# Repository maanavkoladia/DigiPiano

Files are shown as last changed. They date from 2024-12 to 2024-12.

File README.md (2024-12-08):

# DigiPiano

The **DigiPiano** is a velocity-sensitive digital piano designed using **STM32** and **ESP32** microcontrollers. It combines advanced sensor technology, high-quality audio playback, and Bluetooth connectivity to deliver a realistic and modern musical experience.

## Project Overview

- **Key Tracking Mechanism:**
  - Uses **Hall effect sensors** and magnets to detect key presses and releases.
  - Tracks key velocity to simulate the dynamics of a real piano.

- **Audio Playback:**
  - Plays pre-recorded piano note samples stored in external memory.
  - Outputs sound via AUX to speakers or streams wirelessly over Bluetooth.

- **Custom Sustain Circuitry:**
  - Includes a custom-designed sustain circuit to enhance the playing experience.

- **Communication Between Microcontrollers:**
  - The STM32 and ESP32 communicate efficiently using **SPI** and **UART** protocols, enabling seamless data exchange for key detection and audio output.

## Implementation Highlights

- The firmware handles multichannel analog data acquisition and processes it to detect key strokes with precision.
- Audio playback is managed through external memory, ensuring low-latency performance.
- Bluetooth functionality allows for wireless connectivity, enabling modern use cases such as streaming to Bluetooth speakers or devices.
- The hardware design incorporates a custom PCB layout for compactness and reliability, integrating sensors, microcontrollers, and audio components.

## See It in Action

Check out this [Instagram reel](https://www.instagram.com/reel/DDNmyurpquJ/?igsh=Y2NvNWVrb3MxazM1) to see the DigiPiano in action!

The DigiPiano is a versatile and user-friendly project, blending traditional piano functionality with modern digital and IoT capabilities.

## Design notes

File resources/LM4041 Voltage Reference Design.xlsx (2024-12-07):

Goal: design a shunt reference circuit
Jonathan Valvano, EE445L
Desired Vz | 1.5 | volts | 1) pick a desired reference voltage Vz (volts)
Vref | 1.233 | volts | LM4041 parameter
R1 | 47 | kohm | 2) choose a standard resistance value (kohm)
best R2 | 10.17761557 | kohm
Pick R2 | 10 | kohm | 3) pick a standard value for R2 close to best R2
Actual Vref | 1.495340426 | volts | Vz=Vref(1+R2/R1)
Vs | 3.3 | volts | V supply
Rin | 2 | kohm | 4) estimate input impedence on Vz (e.g., to DAC)
Iz | 0.08 | mA | LM4041 parameter
Iref | 0.02623404255 | mA | Vz/(R1+R2), Ohms Law, current through R1,R2
IL | 0.7476702128 | mA | Vz/Rin, Ohms Law, current through Rin
I total | 0.8539042553 | mA | Iz+Iref+IL
max Rs | 2.113421456 | kohm | (Vs-Vz)/Itotal
 |  |  | 5) choose Rs less than max Rs

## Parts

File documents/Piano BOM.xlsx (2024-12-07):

Quantity | REF DES | Type | Description | Manufacturer | Mfg. P/N | Distributor | P/N | Unit cost | Cost | Link | Current (mA)
1 | U | MCU | The TM4C123G LaunchPad evaluation kit is a low-cost evaluation platform for Arm Cortex-M4F based microcontrollers (MCUs). Featuring an 80-MHz Arm Cortex-M4F central processing unit, 256kB of flash and 32 kB of static random access memory, the TM4C123GH6PM MCU provides integrated USB 2.0 support for USB host/device/on-the-go and two 12-bit analog-to-digital converter modules. The TM4C123GH6PM also includes a multitude of serial communication channels such as UART, SPI, I2C, and CAN. The design of the TM4C123G LaunchPad highlights the TM4C123GH6PM USB 2.0 device interface and additional device features such as the hibernation and PWM modules. The EK-TM4C123GXL includes programmable user buttons and an RGB LED for custom applications. The stackable headers provide the interface to connect BoosterPack™ plug-in modules and make it easy and simple to expand the functionality of the TM4C123G LaunchPad through the Texas Instruments BoosterPack ecosystem. The TI-developed TivaWare SDK provides drivers for all peripherals and example code for dozens of applications for the TM4C123G LaunchPad. | TI | EK-TM4C123GXL | TI | EK-TM4C123GXL | 16.99 | 16.99 | https://www.ti.com/tool/EK-TM4C123GXL#order-start-development | 35mA
1 | IC | IC | The TM4C123GH6PM microcontroller is targeted for industrial applications, including remote monitoring, electronic point-of-sale machines, test and measurement equipment, network appliances and switches, factory automation, HVAC and building control, gaming equipment, motion control, transportation, and fire and security. | TI | TM4C123GH6PMIR | TI |  | $9.19 | $9.19 | https://www.ti.com/product/TM4C123GH6PM/part-details/TM4C123GH6PMIR | 30-35 mA, assuming 80Mhz and using perifs
1 | U | MCU | About this item 2.4GHz Dual Mode WiFi + Bluetooth Development Board Ultra-Low power consumption, works perfectly with the Arduino IDE Support LWIP protocol, Freertos SupportThree Modes: AP, STA, and AP+STA ESP32 is a safe, reliable, and scalable to a variety of applications | Espressif | ESP32-WROOM | HiLetgo | ESP-Wroom-32D | $9.99 | $9.99 | https://www.amazon.com/HiLetgo-ESP-WROOM-32-Development-Microcontroller-Integrated/dp/B0718T232Z | 170mA
3 | IC | multichannel-adc | he MCP3008 10-bit Analog-to-Digital Converter (ADC) combines high performance and low power consumption in a small package, making it ideal for embedded control applications. The MCP3008 features a successive approximation register (SAR) architecture and an industry-standard SPI serial interface, allowing 10-bit ADC capability to be added to any PIC® microcontroller. The MCP3008 features 200k samples/second, 8 input channels, low power consumption (5nA typical standby, 425µA typical active), and is available in 16-pin PDIP and SOIC packages. Applications for the MCP3008 include data acquisition, instrumentation and measurement, multi-channel data loggers, industrial PCs, motor control, robotics, industrial automation, smart sensors, portable instrumentation and home medical appliances. | MicroChip | MCP3008 | DigiKey | MCP3008-I/P-ND | $3.12 | $9.36 | https://www.digikey.com/en/products/detail/microchip-technology/MCP3008-I-P/319422 | 300uA
24 | U | sensor | 40Pcs 49E Hall Element S49E SS49E Linear Hall Element Linear Hall Effect Sensors 3 Pins Sensor Element Switch OH49E TO-92S | HoneyWell | SS49E | Jessine | S49E SS49E | $0.32 | $7.77 | https://www.amazon.com/JESSINIE-Element-Linear-Effect-Sensors/dp/B0BXDMRHF8 | 6mA
24 |  | magnet | gerator Magnets 50 Pcs, 10x3mm Tiny Round Disc Small, Muti-use Premium Neodymium Fridge Magnets Rare Earth, Whiteboard Magnets for Crafts, DIY, Office, Dry Erase Board |  |  | VSKIZ |  | $0.13 | $3.35 | https://www.amazon.com/VSKIZ-Refrigerator-Muti-use-Neodymium-Whiteboard/dp/B0BVY5VYQY
24 |  | springs | Made of copper, ,The piano spring adopts fine workmanship, good elasticity and long service life. The piano jack springs are made of high quality brass material and . Replacement piano action part to replace worn, weak or broken jack springs. Remove action, remove spring, clear hole, add drop of glue, put in new spring, put action back in These springs can be used on upright piano keys to replace keys that are not functioning properly due to worn springs |  |  | BQLZR |  | $0.11 | $2.66 | https://www.amazon.com/BQLZR-Golden-Copper-Upright-Replacement/dp/B017OYX4MU
1 | IC | 16bit DAC | AD5541A Digital to Analog Converter (DAC) Data Acquisition Pmod™ Platform Evaluation Expansion Board | Digilent | Pmod DA3 | DigiKey | 1286-1089-ND | $35.99 | $35.99 | https://www.digikey.com/en/products/detail/digilent-inc/410-241/4090066 | 20mA
1 | U | speaker |  |  |  |  |  |  |  |  |  | not sure about this yet
1 | U | linear reg | Linear Voltage Regulator IC Positive Fixed 1 Output 500mA TO-220-3 | TI | LM2937ET-3.3/NOPB | DigiKey | LM2937ET-3.3/NOPB-ND | $1.81 | $1.81 | https://www.digikey.com/en/products/detail/texas-instruments/LM2937ET-3-3-NOPB/363870 | 50uA
1 | IC | microSD Spi brekout | 5PCS Micro SD Card Reader Module Memory Storage Mini TF Card Adapter SPI Interface Breakout Board for Arduino for Raspberry Pi with 40P Jumper Cable | Stededu |  |  |  | $1.80 | $1.80 | https://www.amazon.com/Interface-Arduino-Raspberry-Breakout-Cable%EF%BC%88Pack/dp/B07MTTLF75?s=electronics | 20mA

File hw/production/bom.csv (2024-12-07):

Designator | Footprint | Quantity | Value | LCSC Part #
C1, C2 | CP_Radial_Tantal200mil | 2 | 1uF
C10, C12, C14, C4, C5 | C_Axial_200mil | 5 | 0.1uF
C11, C8 | C_Axial_200mil | 2 | 1uF
C13, C9 | C_Axial_200mil | 2 | 0.01uF
C15 | C_Axial_200mil | 1 | 10uF
C3 | CP_Radial_Tantal200mil | 1 | 2.2uF
C6, C7 | C_Axial_200mil | 2 | 10pF
IC1 | QFP50P1200X1200X160-64N | 1 | TM4C123GH6PMIR
J10_ADC1 | Molex_KK-254_AE-6410-04A_1x04_P2.54mm_Vertical | 1 | ADC1
J11_ADC3 | Molex_KK-254_AE-6410-04A_1x04_P2.54mm_Vertical | 1 | ADC3
J12 | AMASS_XT30UPB-M_1x02_P5.0mm_Vertical | 1 | 3.3V Pads
J13 | AMASS_XT30UPB-M_1x02_P5.0mm_Vertical | 1 | 5V Pads
J1_BARREL | BarrelJack_SwitchcraftConxall_RAPC10U_Horizontal | 1 | Barrel_Jack
J2_JTAG | PinHeader_1x05_P2.54mm_Vertical | 1 | Header_5
J3_DAC | Molex_KK-254_AE-6410-06A_1x06_P2.54mm_Vertical | 1 | Conn_01x06_Socket_DAC
J8_SDCARD | Molex_KK-254_AE-6410-11A_1x11_P2.54mm_Vertical | 1 | LCD SD HEADERS
J9_ADC2 | Molex_KK-254_AE-6410-04A_1x04_P2.54mm_Vertical | 1 | ADC2
R1 | R_Axial_DIN0204_L3.6mm_D1.6mm_P7.62mm_Horizontal | 1 | 10k
R2 | R_Axial_DIN0204_L3.6mm_D1.6mm_P7.62mm_Horizontal | 1 | 1M
SW1 | SW_PUSH_6mm | 1 | RESET
TP13, TP14, TP19, TP20, TP21, TP22, TP23 | Pin_D1.0mm_L10.0mm | 7 | TestPoint
U101_LP_STANDALONE, U30_BACKUP | ti_EKTM4C123GXL | 2 | EK-TM4C123GXL
U29 | T03B | 1 | LM2937ET-3.3/NOPB
U31_ESP32 | MODULE_ESP32-DEVKITC | 1 | ESP32-DEVKITC
Y1 | ABM3 | 1 | ABM3-16.000MHZ-B2-T

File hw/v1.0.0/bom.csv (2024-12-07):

Designator | Footprint | Quantity | Value | LCSC Part #
C101, C102 | C_Axial_L5.1mm_D3.1mm_P15.00mm_Horizontal | 2 | 100nF
C103, C104 | CP_Axial_L10.0mm_D4.5mm_P15.00mm_Horizontal | 2 | 4.7uF
D101 | D_5W_P12.70mm_Horizontal | 1 | 1V0
J101 | Samtec_HPM-02-01-x-S_Straight_1x02_Pitch5.08mm | 1 | EXT_3V3
LS101 | PinHeader_1x02_P2.54mm_Vertical | 1 | Speaker
Q101 | vishay_IRLD024PBF | 1 | IRLD024PBF
R101 | R_Axial_DIN0411_L9.9mm_D3.6mm_P15.24mm_Horizontal | 1 | 10k
SW101 | SW_PUSH_6mm | 1 | UP
SW102 | SW_PUSH_6mm | 1 | DOWN
SW103 | SW_PUSH_6mm | 1 | LEFT
SW104 | SW_PUSH_6mm | 1 | RIGHT
SW105 | SW_PUSH_6mm | 1 | MODE
U101 | ti_EKTM4C123GXL | 1 | EK-TM4C123GXL
U102 | ai_thinker_ESP8266_01 | 1 | ESP8266-01/ESP-01
U103 | adafruit_st7735r | 1 | Adafruit ST7735R

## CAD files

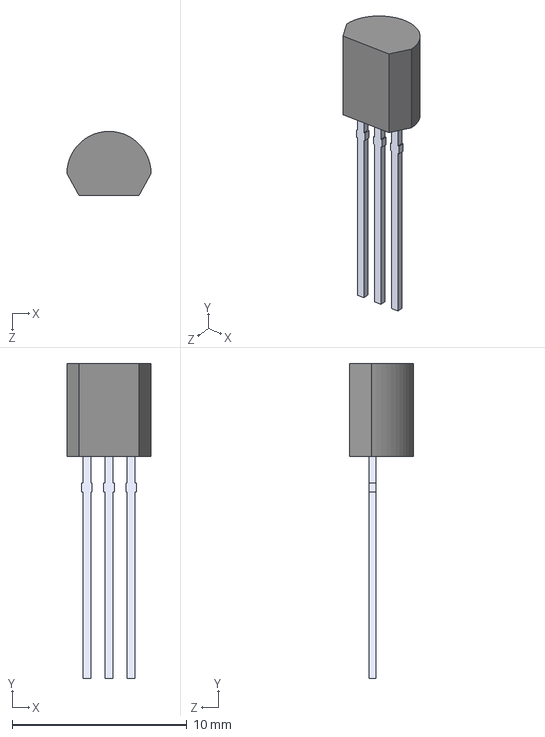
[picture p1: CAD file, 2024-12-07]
hw/models/ti_LM4041CILPR.step
4.82 x 18.0 x 3.68 mm

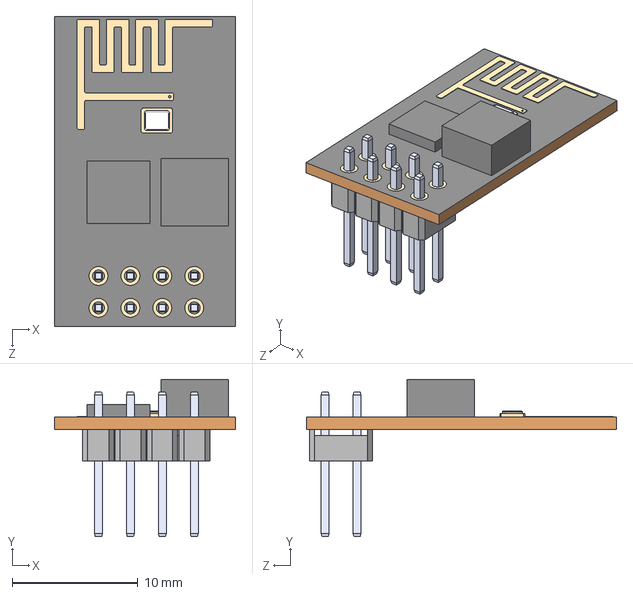
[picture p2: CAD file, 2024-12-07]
hw/models/ai_thinker_ESP8266-01.step
14.4 x 12.5 x 24.7 mm

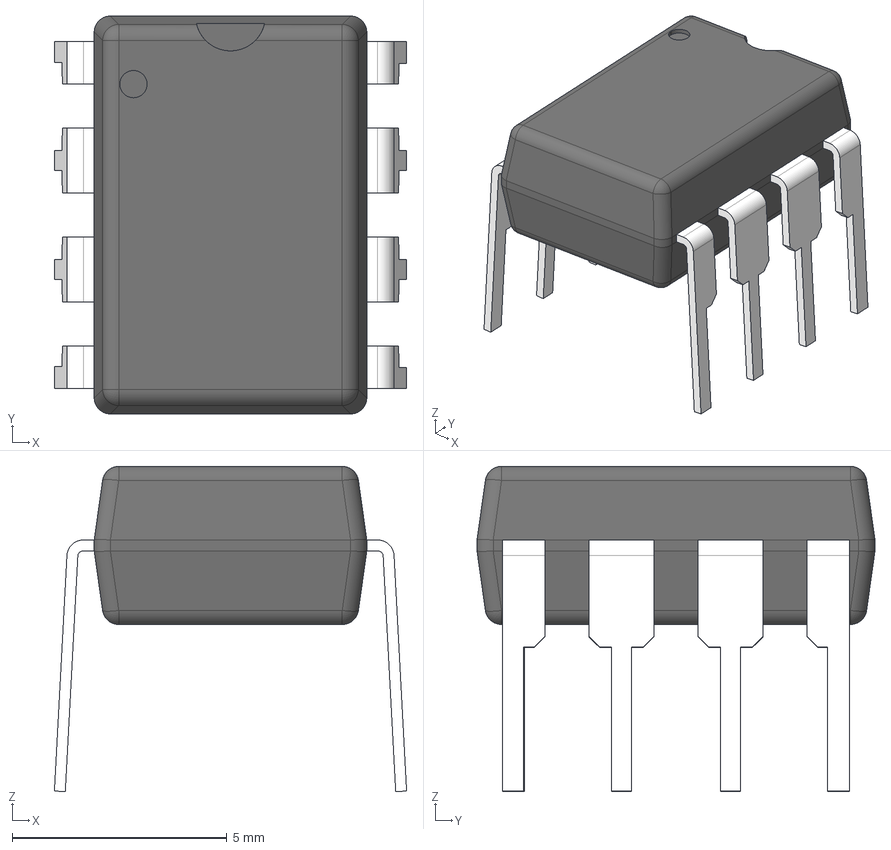
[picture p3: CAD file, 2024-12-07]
hw/models/ti_TLV5618AIP.stp
8.20 x 9.27 x 7.58 mm
BODY_P0008A
LEAD_P0008A x 4
LD_LHALF_P0008A x 2
LD_RHALF_P0008A x 2

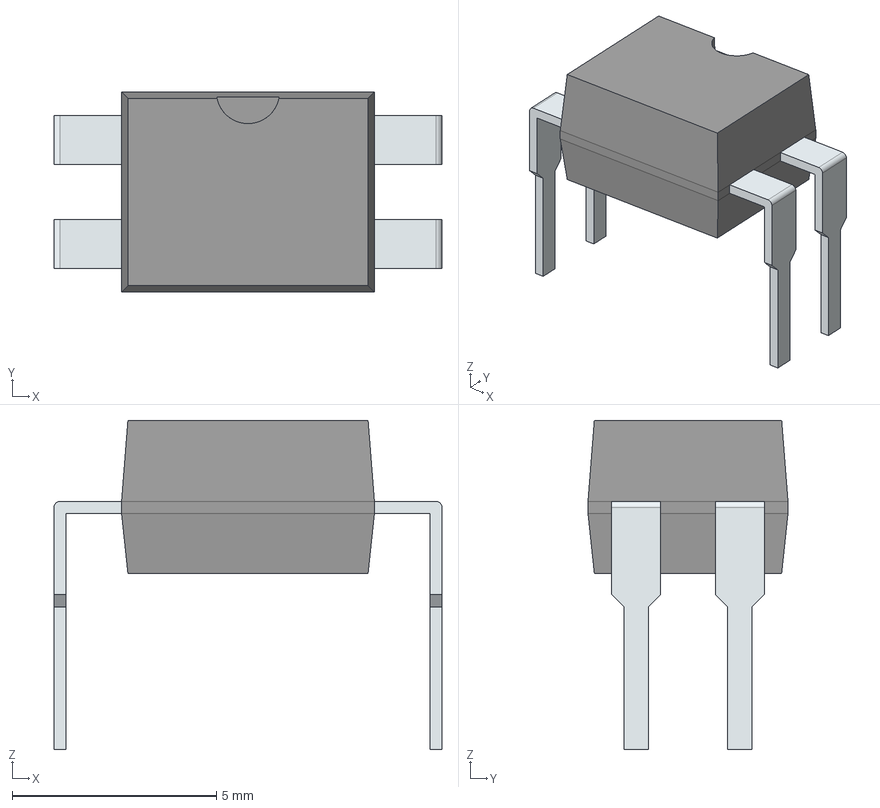
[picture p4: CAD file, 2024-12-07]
hw/models/vishay_IRLD024PBF.stp
9.51 x 4.90 x 8.07 mm
PinsArrayLR

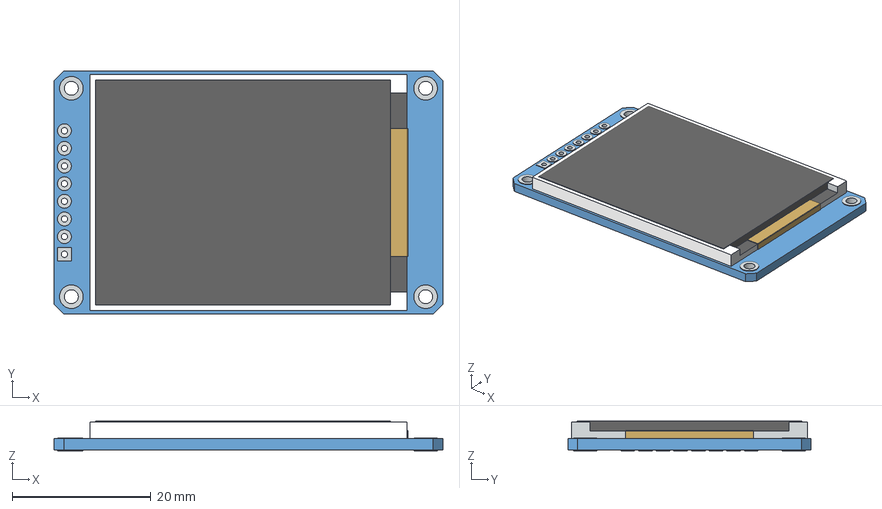
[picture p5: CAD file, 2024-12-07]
hw/models/adafruit_st7735r.stp
56.0 x 35.0 x 4.25 mm

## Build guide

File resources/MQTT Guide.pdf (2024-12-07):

## Contents

Lab 4 MQTT Writeup | 2

The Mobile App makes a change to thermostat temperature or

1

## Lab 4 MQTT Writeup

Key Aspects of MQTT

MQTT (Message Queuing Telemetry Transport), is a lightweight messaging protocol designed for low-bandwidth, high-latency, and unreliable networks. Developed in 1999 by IBM, MQTT is now a widely used open standard. MQTT is useful as it can:

- Organize data at the protocol level
- Cordinate actions between IOT devices
- Allow easy centralization of data to user-facing dashboards
- Send connected clients only the data they need
- Ensure a Quality Of Service (QOS) of data sent by clients

MQTT topology and the Publish/Subscribe Model:

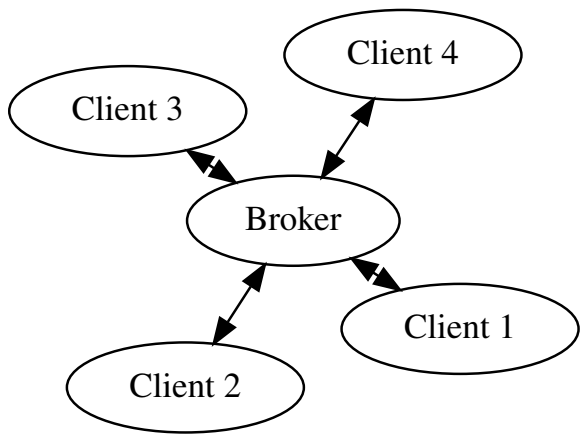
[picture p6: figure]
Broker; Client 1; Client 2; Client 3; Client 4

Figure 1: MQTT Client-Broker topology

MQTT includes ONLY broker to client/client to broker comunications. MQTT networks have one broker which facilitates comunication between many clients.

MQTT uses a Publish/Subscribe Model. In this model, data movement is controled by topics. Clients decide what data they recive, by deciding what topics they subscribe to. Clients can influence where data is sent by choosing what topic they attach to the data they publish. The messages sent and recived allways consist of a topic & data.

Although the broker is responsible for relaying data, it has no discresion to decide where data goes. The broker will relay a published message from any client to all clients that are subscribed to the topic of the message.

2

Topic Naming scheme:

An MQTT topic is a hierarchical string identifier that categorizes messages being published/subscribed to within the MQTT system. Topics are represented as strings and are organized hierarchically using forward slashes (‘/’). For example, a topic could be

"sensors/temperature/EER/floor1/embeddedlab."

or

"EER/floor1/embeddedlab/temperature"

How topics are defined are up to you. As long as they follow the typical hierarchical format.

Example of MQTT Communication

Here is an example of a typical MQTT communication between clients and how the broker routes it.

1. An MQTT client publishes a message to a specific topic on the MQTT broker.
2. The MQTT broker receives the published message and examines the topic.
3. The broker checks its subscription database to determine which MQTT client have subscribed to that topic.
4. The broker forwards the message to all subscribed clients
5. Subscribed MQTT clients receive the message and can take action based on its content.

Now lets imagine a scenario where we have a IoT setup in the EER. We have a three sensors which are their very own internet conected devices located in the EER. We have a temperature sensor in the 445L lab room, a thermostat located in the 319K room (let’s imagine the thermostat controls the A.C for the entirety of floor 1), and a faculty member has a mobile app that allows him to control the thermostat or see the readings from the sensors.

Here we have three clients:

- 445L Temperature Sensor
– Can read temperature in the 445L room
- 319K Lab Thermostat
– Connected via wire to the A.C, can control the A.C for the entirety of floor 1.
– Has its own temperature sensor that allows it to read the temperature in the room it is in (the 319K lab in this case)

3

– Has a temperature the thermostat can be set too. If the temperature in any of the rooms dip/rise above this temperature. The A.C is enabled to heat/cool
– Has a mode for the A.C. The A.C can either be off, set to cool, or set to heat.
– Can interface with external temperature sensors (such as the 445L temperature sensor)
– This closely resembles popular IoT thermostats such as the Nest or Ecobee
- Mobile App
– Allows you to control the thermostat (mode, set temperature)
– Read the temperature readings across all temperature sensors

All of these clients are connected to one central server (The MQTT Broker) to faciliate communication. This server could be for examples McDermott MQTT server in his office, or a public/cloud based MQTT Server.

Figure 2: Client-Broker setup of the Example

Now lets try to analyze what information each client provides, and what information each client would want from another client.

- 445L Temperature Sensor
– Reads the 445l lab room temperature, publishes it.
- 319K Lab Thermostat
– Reads the temperature in the 319K room, can act on this reading (enable the A.C for floor 1). Can also publish it (for the mobile app) – Is interested in the temperature in the 445L room, can act on this reading (enable the A.C for floor 1)
– Has a temperature that can be set to enable cooling/heat (acting on this data) It can publish this temperature (for the mobile app), and it can also have this changed externally (from the mobile app)
– Has a A.C mode (off/cool/heat). It acts on this mode (enable the A.C for cool/hot if the outside temperature changes). It can publish this data (so the mobile app knows the current A.C mode), it can also have this changed externally (from the mobile app)
- Mobile App
– Can set the A.C mode from the mobile app. Changes to this can be made from app or thermostate

4

– Can set the thermostat temperature. Changes can be made from app or thermostat.
– Can read all temperature sensor readings.

From this lets define the following topics, and these publishers and subscribers

- /EER/floor1/445Lab/temperature
- Publishers:
- 445L Temperature Sensor
- Subscribers:
- 319K Thermostat
- Mobile App
- /EER/floor1/319KLab/temperature
- Publishers:
- 319K Thermostat
- Subscribers:
- Mobile App
- /EER/floor1/thermostat/set_temp
- Publishers:
- 319K Thermostat
- Mobile App
- Subscribers:
- 319K Thermostat
- Mobile App
- /EER/floor1/thermostat/mode
- Publishers:
- 319K Thermostat
- Mobile App
- Subscribers:
- 319K Thermostat
- Mobile App

The scenario where 445L Lab Temp Changes

If the 445L lab room temperature changes. The sensor publishes to its topic its payload.

5

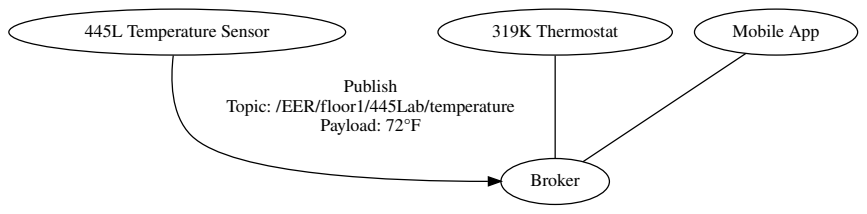
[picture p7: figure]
Broker; 445L Temperature Sensor; Publish Topic: /EER/floor1/445Lab/temperature Payload: 72°F; 319K Thermostat; Mobile App

Figure 3: 445L Temperature Sensor publishes change

The thermostat, and mobile app are subscribers and therefore notified.

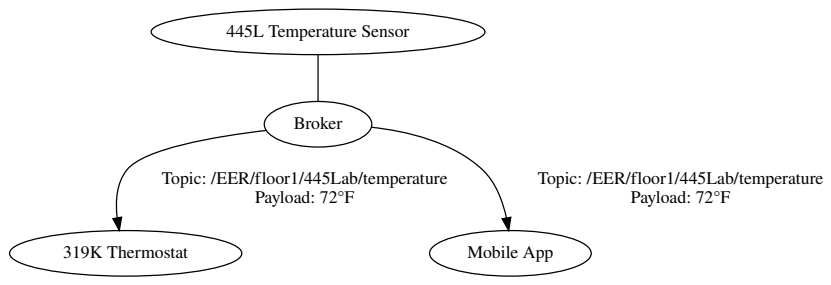
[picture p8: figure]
Broker; 319K Thermostat; Topic: /EER/floor1/445Lab/temperature Payload: 72°F; Mobile App; 445L Temperature Sensor

Figure 4: Subscribers are notified

The thermostat could act on this change. For example if the temperature 72°F exceeds/below the set temperature, it could enable the A.C. The mobile app also now has up-to date sensor reading.

The scenario where 319K Lab temp changes.

The thermostat has it’s own temperature sensor measuring the temperature of the 319K room. The thermostat can act this temperature (enable the A.C for example). But the mobile app also wants to be up-to date regarding all temperature readings.

6

Figure 5: Thermostat Temperature Sensor publishes change

The mobile app is subscribed to the all temperature readings, including the

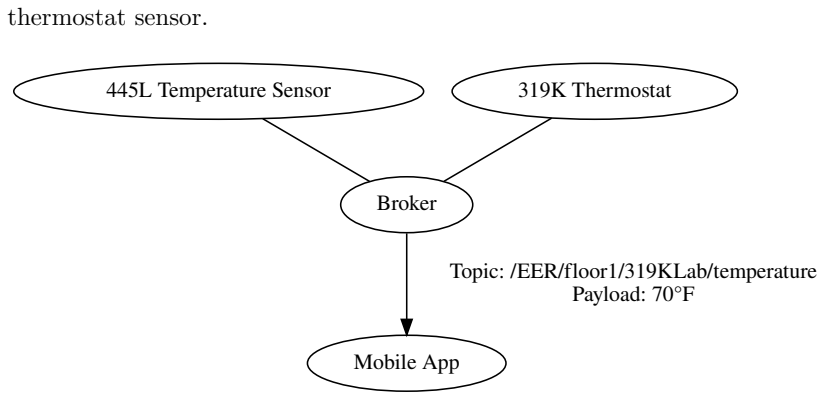
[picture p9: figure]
thermostat sensor.; Broker; Mobile App; Topic: /EER/floor1/319KLab/temperature Payload: 70°F; 445L Temperature Sensor; 319K Thermostat

Figure 6: Subscribers are notified

Thermostat has a change in set temperature or mode.

If you were to change the set temperature on the thermostat.

Figure 7: Thermostat Set Temp changes

The mobile app will be notified.

7

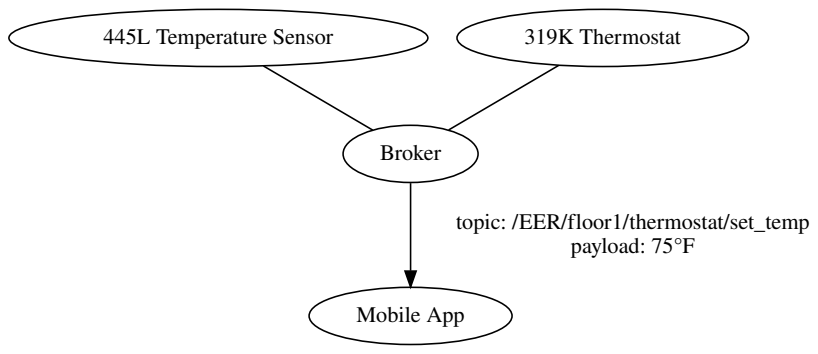
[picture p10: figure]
Broker; Mobile App; topic: /EER/floor1/thermostat/set_temp payload: 75°F; 445L Temperature Sensor; 319K Thermostat

Figure 8: Subscribers are notified

Similarily if you were to change the mode from “heat” to “cool” on the thermostat

Figure 9: Thermostat Set Temp changes

The mobile app will be notified.

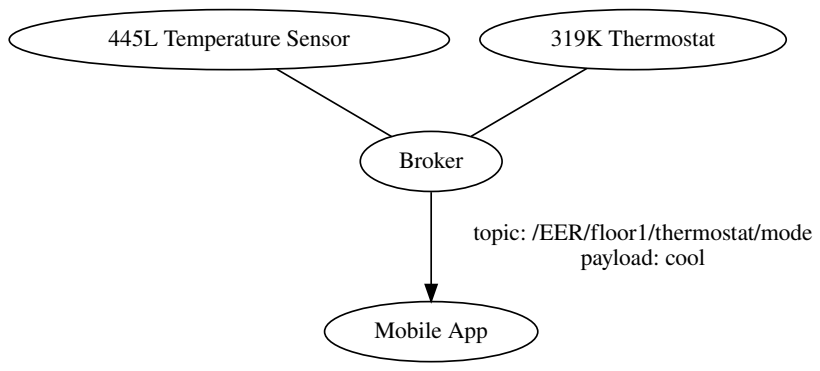
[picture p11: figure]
Broker; Mobile App; topic: /EER/floor1/thermostat/mode payload: cool; 445L Temperature Sensor; 319K Thermostat

Figure 10: Subscribers are notified

8

The Mobile App makes a change to thermostat temperature or mode

If we want to change the set temperature of the thermostat from the mobile app.

Figure 11: Thermostat Set Temp changes from Mobile App

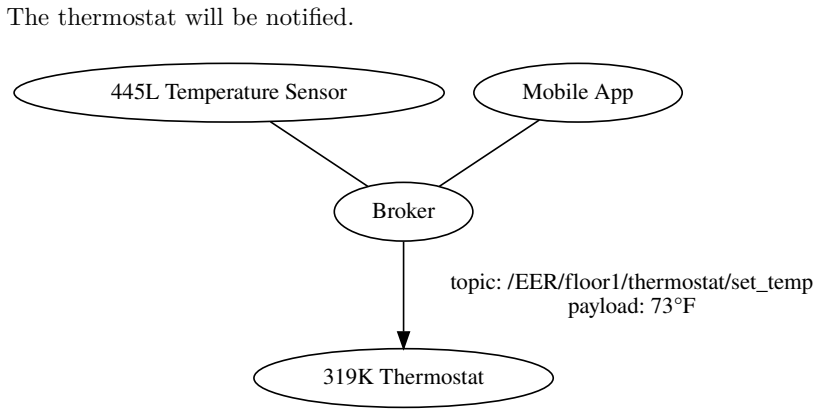
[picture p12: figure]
The thermostat will be notified.; Broker; 319K Thermostat; topic: /EER/floor1/thermostat/set_temp payload: 73°F; 445L Temperature Sensor; Mobile App

Figure 12: Subscribers are notified

Similarily if we want to turn off the A.C from the mobile app.

Figure 13: Thermostat Mode changes from Mobile App

The thermostat will be notified.

9

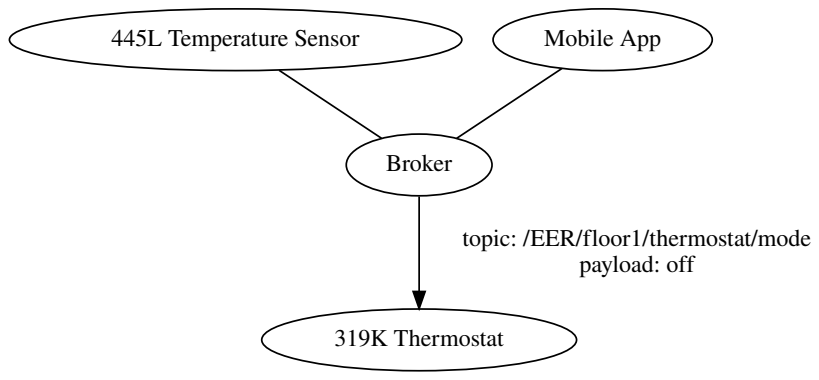
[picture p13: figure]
Broker; 319K Thermostat; topic: /EER/floor1/thermostat/mode payload: off; 445L Temperature Sensor; Mobile App

Figure 14: Subscribers are notified

How to approach Lab 4

From the perspective of the lab we have two clients:

- Your Alarm Clock
- The web dashboard

and a broker (the free broker service we are using called emqx.io).

From the perspective of the free broker service however, it has your alarm clock and web dashboard as a client. As well as the alarm clock and web dashboard of everyone else in the class (and anyone else using the service). So when you define your topics make sure the topic string is unique. For example if everyone used the same topic, lets say “alarm/current_time”, you would be able to change the time of everyones alarm clock. So to make unique topic names, your topic should start with your eid, ex. “eid123/alarm/current_time”.

Here is how we reccomend approaching this lab to avoid stress and headaches. First things first, don’t try integrating lab3 right away, instead get topics working.

Using the starter code, do the following.

1. ESP Bring up, the ESP8266 should be able to connect to a network and to the broker. This should be done in prep. Come to your TA’s if you were unable to do this.
2. Define your topics, and the subscriber/publisher relationships.
3. Have both of you open the web dashboard. Have one person subscribe to a topic, and have the other publish to the topic. The subscriber should be able to receive a message when this happens.
4. Modify your TM4C starter code so you can communicate with the ESP. The TM4C communicates with the ESP over UART. You can observe what

10 is being sent to the ESP via USB-Serial between your PC and the TM4C using a serial terminal.
5. Test, can you publish to a topic from the TM4C, do you see this change reflected on the web dashboard?
6. Test, can you publish to a topic from the web dashboard, do you see this change reflected on the TM4C?
7. Now that you can publish/subscribe to topics. Now integrate your Lab 3 Code.

If you need any help, please email us or come to our office hours.

11

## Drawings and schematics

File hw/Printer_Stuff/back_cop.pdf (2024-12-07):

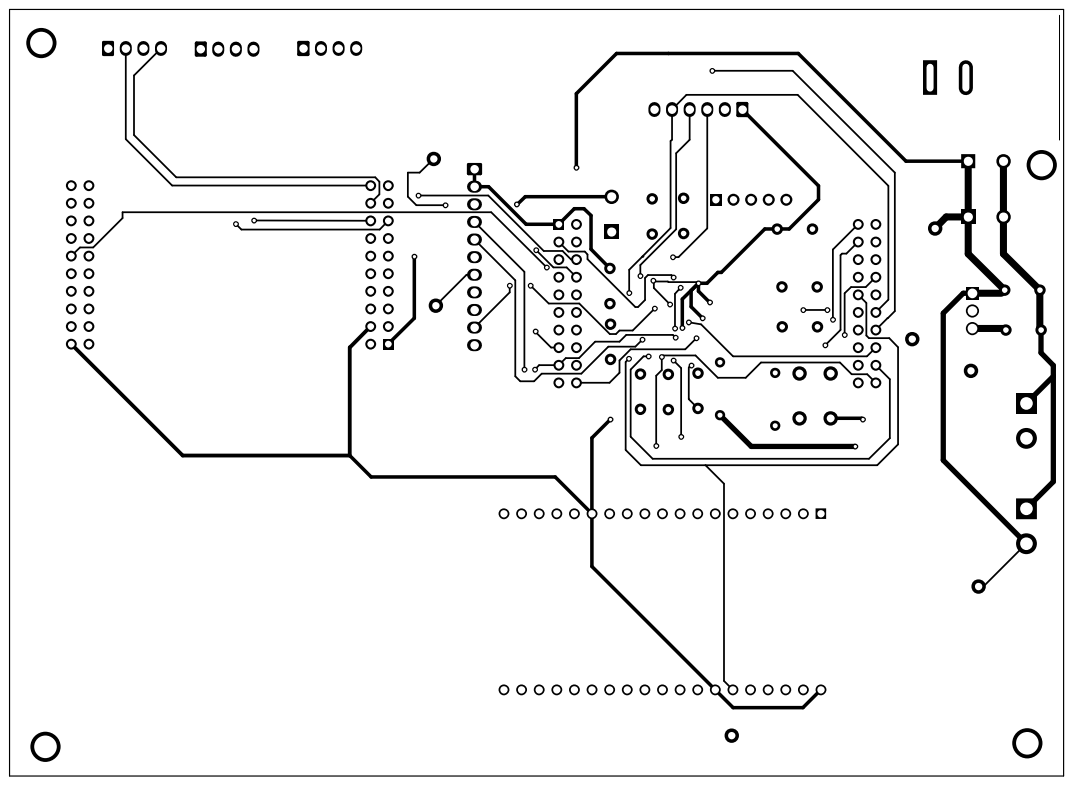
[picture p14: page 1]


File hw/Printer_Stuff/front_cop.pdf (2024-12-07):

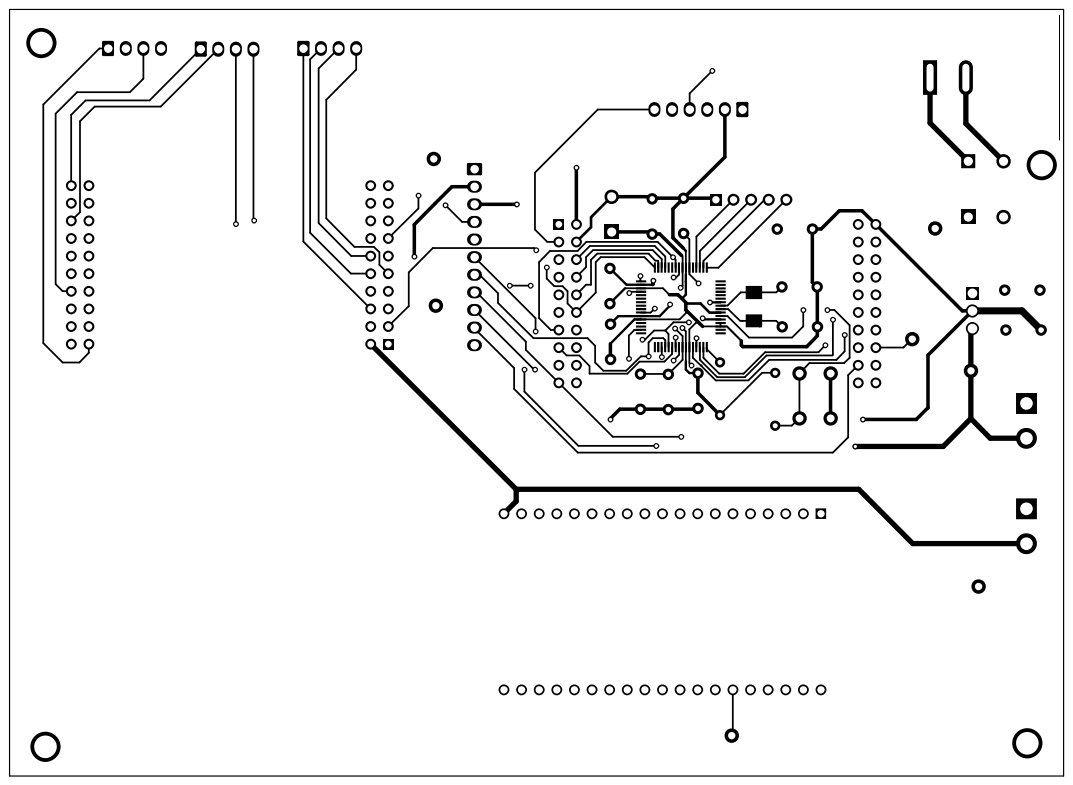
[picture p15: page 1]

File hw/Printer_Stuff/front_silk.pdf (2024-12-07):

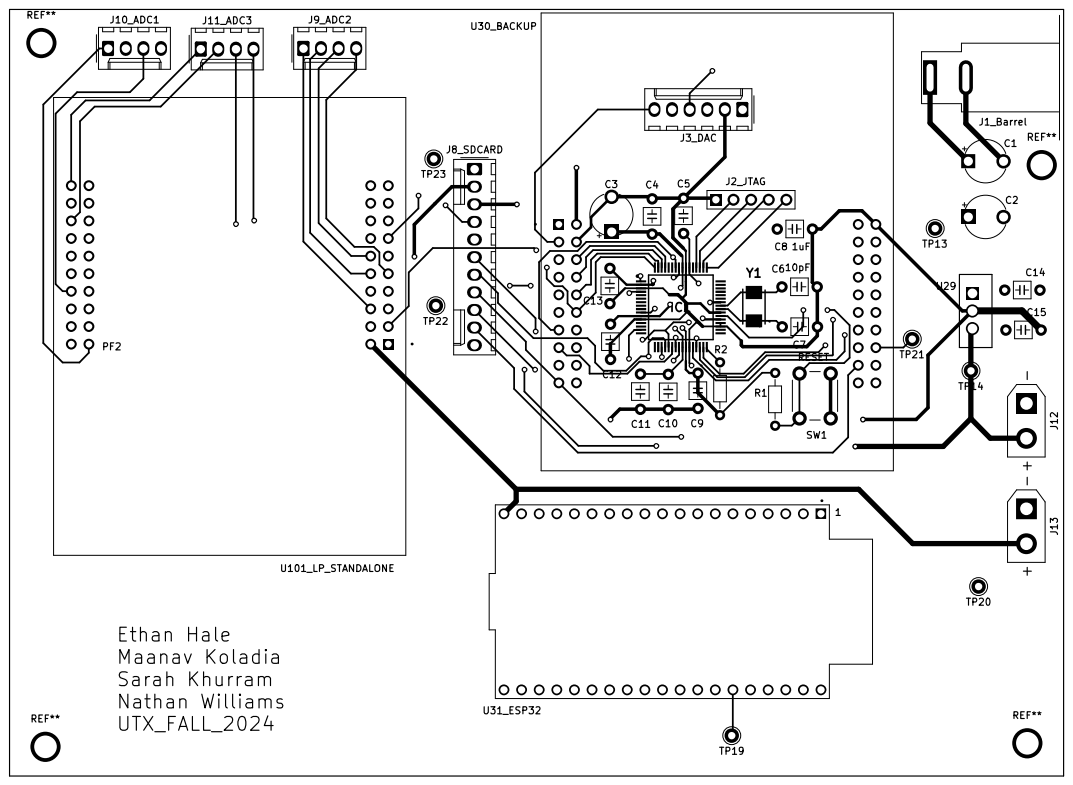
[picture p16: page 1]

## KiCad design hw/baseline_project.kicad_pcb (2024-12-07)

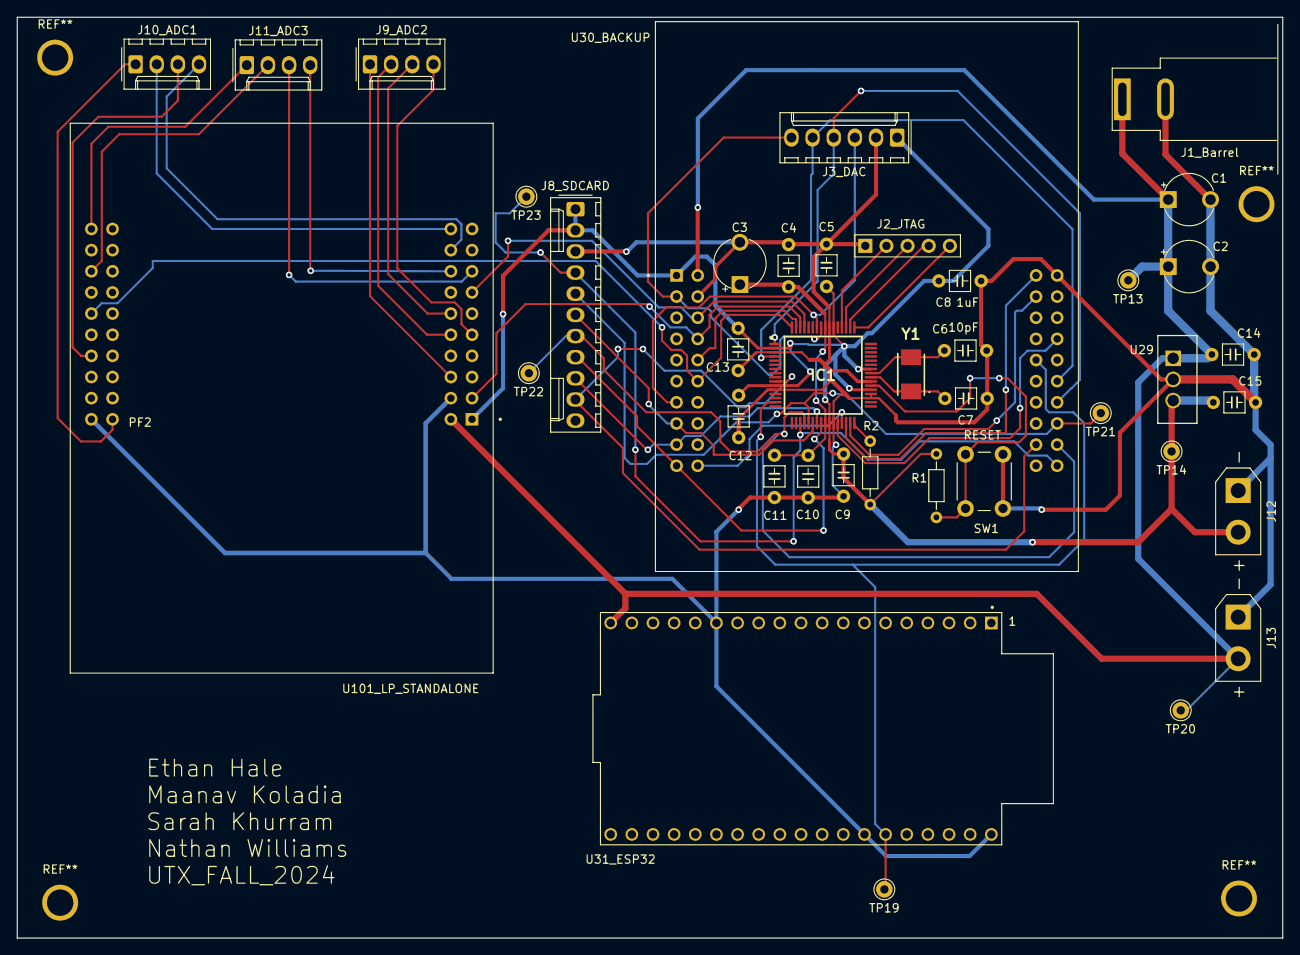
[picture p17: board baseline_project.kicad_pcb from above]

Board: 2 copper layers, 152.0 x 110.6 mm, 40 parts (0 on the bottom side), 44 nets.

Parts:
C1, C2: 1uF; CP_Radial_Tantal200mil
C3: 2.2uF; CP_Radial_Tantal200mil
C4, C5, C10, C12, C14: 0.1uF; C_Axial_200mil
C6, C7: 10pF; C_Axial_200mil
C8, C11: 1uF; C_Axial_200mil
C9, C13: 0.01uF; C_Axial_200mil
C15: 10uF; C_Axial_200mil
IC1: TM4C123GH6PMIR; QFP50P1200X1200X160-64N
J1_Barrel: Barrel_Jack; BarrelJack_SwitchcraftConxall_RAPC10U_Horizontal
J2_JTAG: Header_5; PinHeader_1x05_P2.54mm_Vertical
J3_DAC: Conn_01x06_Socket_DAC; Molex_KK-254_AE-6410-06A_1x06_P2.54mm_Vertical
J8_SDCARD: LCD SD HEADERS; Molex_KK-254_AE-6410-11A_1x11_P2.54mm_Vertical
J9_ADC2: ADC2; Molex_KK-254_AE-6410-04A_1x04_P2.54mm_Vertical
J10_ADC1: ADC1; Molex_KK-254_AE-6410-04A_1x04_P2.54mm_Vertical
J11_ADC3: ADC3; Molex_KK-254_AE-6410-04A_1x04_P2.54mm_Vertical
J12: 3.3V Pads; AMASS_XT30UPB-M_1x02_P5.0mm_Vertical
J13: 5V Pads; AMASS_XT30UPB-M_1x02_P5.0mm_Vertical
R1: 10k; R_Axial_DIN0204_L3.6mm_D1.6mm_P7.62mm_Horizontal
R2: 1M; R_Axial_DIN0204_L3.6mm_D1.6mm_P7.62mm_Horizontal
SW1: RESET; SW_PUSH_6mm
TP13, TP14, TP19, TP20, TP21, TP22, TP23: TestPoint; Pin_D1.0mm_L10.0mm
U29: LM2937ET-3.3/NOPB; T03B
U30_BACKUP, U101_LP_STANDALONE: EK-TM4C123GXL; ti_EKTM4C123GXL
U31_ESP32: ESP32-DEVKITC; MODULE_ESP32-DEVKITC
Y1: ABM3-16.000MHZ-B2-T; ABM3

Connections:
+3V3: C5.1, C8.1, C9.1, C12.1, C13.1, C15.1, IC1.2 (VDDA), IC1.11 (VDD_1), IC1.26 (VDD_2), IC1.37 (VBAT), IC1.42 (VDD_3), IC1.54 (VDD_4), J3_DAC.1, J8_SDCARD.1, J8_SDCARD.2, J12.2, R1.1, R2.1, TP14.1, U29.3 (OUT), U30_BACKUP.J1_1 (+3.3V), U101_LP_STANDALONE.J1_1 (+3.3V)
+5V: C1.1, C2.1, C14.1, J1_Barrel.1, J13.2, TP13.1, TP20.1, U29.1 (IN), U30_BACKUP.J3_1 (+VBUS), U31_ESP32.19 (EXT_5V), U101_LP_STANDALONE.J3_1 (+VBUS)
/LD0: C3.1, C4.1, C10.1, C11.1, IC1.25 (VDDC_1), IC1.56 (VDDC_2)
GND: C1.2, C2.2, C3.2, C4.2, C5.2, C6.2, C7.1, C8.2, C9.2, C10.2, C11.2, C12.2, C13.2, C14.2, C15.2, IC1.3 (GNDA), IC1.12 (GND_1), IC1.27 (GND_2), IC1.35 (GNDX), IC1.36 (XOSC1), IC1.39 (GND_3), IC1.55 (GND_4), J1_Barrel.2, J2_JTAG.1 (A), J3_DAC.2, J8_SDCARD.3, J12.1, J13.1, SW1.1, U29.2 (GND), U30_BACKUP.J2_1 (GND), U30_BACKUP.J3_2 (GND), U31_ESP32.14 (GND1), U31_ESP32.32 (GND2), U31_ESP32.38 (GND3), U101_LP_STANDALONE.J2_1 (GND), U101_LP_STANDALONE.J3_2 (GND)
IO21: IC1.15 (PC5), TP19.1, U30_BACKUP.J4_5 (PC5), U31_ESP32.33 (IO21)
LP_PA2: J11_ADC3.1, U101_LP_STANDALONE.J2_10 (PA2)
LP_PA4: J11_ADC3.2, U101_LP_STANDALONE.J2_8 (PA4)
LP_PA5: J11_ADC3.3, U101_LP_STANDALONE.J1_8 (PA5)
LP_PB4: IC1.61 (PD0), U30_BACKUP.J3_3 (PD0), U101_LP_STANDALONE.J1_7 (PB4)
LP_PB5: IC1.62 (PD1), U30_BACKUP.J3_4 (PD1), U101_LP_STANDALONE.J1_2 (PB5)
LP_PB7: IC1.64 (PD3), U30_BACKUP.J3_6 (PD3), U101_LP_STANDALONE.J2_6 (PB7)
LP_PD0: J9_ADC2.1, U101_LP_STANDALONE.J3_3 (PD0)
LP_PD2: J9_ADC2.2, U101_LP_STANDALONE.J3_5 (PD2)
LP_PD3: J9_ADC2.3, U101_LP_STANDALONE.J3_6 (PD3)
LP_PE2: J11_ADC3.4, U101_LP_STANDALONE.J3_8 (PE2)
LP_PE3: J10_ADC1.4, U101_LP_STANDALONE.J3_9 (PE3)
LP_PE4: J9_ADC2.4, U101_LP_STANDALONE.J1_5 (PE4)
LP_PF0: J10_ADC1.3, U101_LP_STANDALONE.J2_4 (PF0)
LP_PF1: J10_ADC1.2, U101_LP_STANDALONE.J3_10 (PF1)
LP_PF2: J10_ADC1.1, U101_LP_STANDALONE.J4_1 (PF2)
unnamed: C7.2, IC1.40 (OSC0), Y1.1
unnamed: C6.1, IC1.41 (OSC1), Y1.2
unnamed: IC1.52 (PC0/TCK/SWCLK), J2_JTAG.2 (B)
unnamed: IC1.51 (PC1/TMS/SWDIO), J2_JTAG.3 (C)
unnamed: IC1.50 (PC2/TDI), J2_JTAG.4 (C)
unnamed: IC1.49 (PC3/TDO/SWO), J2_JTAG.5 (C)
unnamed: IC1.38 (~RST), R1.2, SW1.2
unnamed: IC1.32 (~WAKE), R2.2
TM_PA2: IC1.19 (PA2/SSI0C1K), J8_SDCARD.4, TP23.1, U30_BACKUP.J2_10 (PA2)
TM_PA3: IC1.20 (PA3/SSI0FSS), J8_SDCARD.7, TP22.1, U30_BACKUP.J2_9 (PA3)
TM_PA4: IC1.21 (PA4/SSI0RX), J8_SDCARD.5, TP21.1, U30_BACKUP.J2_8 (PA4)
TM_PA5: IC1.22 (PA5/SSI0TX), J8_SDCARD.6, U30_BACKUP.J1_8 (PA5)
TM_PA6: IC1.23 (PA6), J8_SDCARD.9, U30_BACKUP.J1_9 (PA6)
TM_PA7: IC1.24 (PA7), J8_SDCARD.8, U30_BACKUP.J1_10 (PA7)
TM_PB4: IC1.58 (PB4), J3_DAC.3, U30_BACKUP.J1_7 (PB4)
TM_PB5: IC1.57 (PB5), J3_DAC.6, U30_BACKUP.J1_2 (PB5)
TM_PB6: IC1.1 (PB6), J3_DAC.4, U30_BACKUP.J2_7 (PB6)
TM_PB7: IC1.4 (PB7), J3_DAC.5, U30_BACKUP.J2_6 (PB7)
TM_PD2: IC1.63 (PD2), U30_BACKUP.J3_5 (PD2)
TM_PD7: IC1.10 (PD7), J8_SDCARD.10, U30_BACKUP.J4_9 (PD7)
TM_PF0: IC1.28 (PF0), U30_BACKUP.J2_4 (PF0)
TM_PF1: IC1.29 (PF1), U30_BACKUP.J3_10 (PF1)
TM_PF2: IC1.30 (PF2), U30_BACKUP.J4_1 (PF2)
TM_PF3: IC1.31 (PF3), U30_BACKUP.J4_2 (PF3)

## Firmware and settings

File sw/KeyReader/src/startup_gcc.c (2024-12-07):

//*****************************************************************************
//
// startup_gcc.c - Startup code for use with GNU tools.
//
// Copyright (c) 2012 Texas Instruments Incorporated.  All rights reserved.
// Software License Agreement
//
// Texas Instruments (TI) is supplying this software for use solely and
// exclusively on TI's microcontroller products. The software is owned by
// TI and/or its suppliers, and is protected under applicable copyright
// laws. You may not combine this software with "viral" open-source
// software in order to form a larger program.
//
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
// This is part of revision 9453 of the EK-LM4F120XL Firmware Package.
//
//*****************************************************************************

#include <stdint.h>
#include "../inc/hw_nvic.h"
#include "../inc/hw_types.h"
#include "../inc/tm4c123gh6pm.h"

//*****************************************************************************
//
// Forward declaration of the fault handlers.
//
//*****************************************************************************
void ResetISR(void);
void NMI_Handler(void) __attribute__((weak));
void HardFault_Handler(void) __attribute__((weak));
void MemManage_Handler(void) __attribute__((weak));
void BusFault_Handler(void) __attribute__((weak));
void UsageFault_Handler(void) __attribute__((weak));
void SVC_Handler(void) __attribute__((weak));
void DebugMon_Handler(void) __attribute__((weak));
void PendSV_Handler(void) __attribute__((weak));
void SysTick_Handler(void) __attribute__((weak));
void IntDefaultHandler(void) __attribute__((weak));

//*****************************************************************************
//
// Weak prototypes of ISR handlers
//
//*****************************************************************************

void GPIOPortA_Handler(void) __attribute__((weak));
void GPIOPortB_Handler(void) __attribute__((weak));
void GPIOPortC_Handler(void) __attribute__((weak));
void GPIOPortD_Handler(void) __attribute__((weak));
void GPIOPortE_Handler(void) __attribute__((weak));
void UART0_Handler(void) __attribute__((weak));
void UART1_Handler(void) __attribute__((weak));
void SSI0_Handler(void) __attribute__((weak));
void I2C0_Handler(void) __attribute__((weak));
void PWM0Fault_Handler(void) __attribute__((weak));
void PWM0Generator0_Handler(void) __attribute__((weak));
void PWM0Generator1_Handler(void) __attribute__((weak));
void PWM0Generator2_Handler(void) __attribute__((weak));
void Quadrature0_Handler(void) __attribute__((weak));
void ADC0Seq0_Handler(void) __attribute__((weak));
void ADC0Seq1_Handler(void) __attribute__((weak));
void ADC0Seq2_Handler(void) __attribute__((weak));
void ADC0Seq3_Handler(void) __attribute__((weak));
void WDT_Handler(void) __attribute__((weak));
void Timer0A_Handler(void) __attribute__((weak));
void Timer0B_Handler(void) __attribute__((weak));
void Timer1A_Handler(void) __attribute__((weak));
void Timer1B_Handler(void) __attribute__((weak));
void Timer2A_Handler(void) __attribute__((weak));
void Timer2B_Handler(void) __attribute__((weak));
void Comp0_Handler(void) __attribute__((weak));
void Comp1_Handler(void) __attribute__((weak));
void Comp2_Handler(void) __attribute__((weak));
void SysCtl_Handler(void) __attribute__((weak));
void FlashCtl_Handler(void) __attribute__((weak));
void GPIOPortF_Handler(void) __attribute__((weak));
void GPIOPortG_Handler(void) __attribute__((weak));
void GPIOPortH_Handler(void) __attribute__((weak));
void UART2_Handler(void) __attribute__((weak));
void SSI1_Handler(void) __attribute__((weak));
void Timer3A_Handler(void) __attribute__((weak));
void Timer3B_Handler(void) __attribute__((weak));
void I2C1_Handler(void) __attribute__((weak));
void Quadrature1_Handler(void) __attribute__((weak));
void CAN0_Handler(void) __attribute__((weak));
void CAN1_Handler(void) __attribute__((weak));
void CAN2_Handler(void) __attribute__((weak));
void Ethernet_Handler(void) __attribute__((weak));
void Hibernate_Handler(void) __attribute__((weak));
void USB0_Handler(void) __attribute__((weak));
void PWM0Generator3_Handler(void) __attribute__((weak));
void uDMA_Handler(void) __attribute__((weak));
void uDMA_Error(void) __attribute__((weak));
void ADC1Seq0_Handler(void) __attribute__((weak));
void ADC1Seq1_Handler(void) __attribute__((weak));
void ADC1Seq2_Handler(void) __attribute__((weak));
void ADC1Seq3_Handler(void) __attribute__((weak));
void I2S0_Handler(void) __attribute__((weak));
void ExtBus_Handler(void) __attribute__((weak));
void GPIOPortJ_Handler(void) __attribute__((weak));
void GPIOPortK_Handler(void) __attribute__((weak));
void GPIOPortL_Handler(void) __attribute__((weak));
void SSI2_Handler(void) __attribute__((weak));
void SSI3_Handler(void) __attribute__((weak));
void UART3_Handler(void) __attribute__((weak));
void UART4_Handler(void) __attribute__((weak));
void UART5_Handler(void) __attribute__((weak));
void UART6_Handler(void) __attribute__((weak));
void UART7_Handler(void) __attribute__((weak));
void I2C2_Handler(void) __attribute__((weak));
void I2C3_Handler(void) __attribute__((weak));
void Timer4A_Handler(void) __attribute__((weak));
void Timer4B_Handler(void) __attribute__((weak));
void Timer5A_Handler(void) __attribute__((weak));
void Timer5B_Handler(void) __attribute__((weak));
void WideTimer0A_Handler(void) __attribute__((weak));
void WideTimer0B_Handler(void) __attribute__((weak));
void WideTimer1A_Handler(void) __attribute__((weak));
void WideTimer1B_Handler(void) __attribute__((weak));
void WideTimer2A_Handler(void) __attribute__((weak));
void WideTimer2B_Handler(void) __attribute__((weak));
void WideTimer3A_Handler(void) __attribute__((weak));
void WideTimer3B_Handler(void) __attribute__((weak));
void WideTimer4A_Handler(void) __attribute__((weak));
void WideTimer4B_Handler(void) __attribute__((weak));
void WideTimer5A_Handler(void) __attribute__((weak));
void WideTimer5B_Handler(void) __attribute__((weak));
void FPU_Handler(void) __attribute__((weak));
void PECI0_Handler(void) __attribute__((weak));
void LPC0_Handler(void) __attribute__((weak));
void I2C4_Handler(void) __attribute__((weak));
void I2C5_Handler(void) __attribute__((weak));
void GPIOPortM_Handler(void) __attribute__((weak));
void GPIOPortN_Handler(void) __attribute__((weak));
void Quadrature2_Handler(void) __attribute__((weak));
void Fan0_Handler(void) __attribute__((weak));
void GPIOPortP_Handler(void) __attribute__((weak));
void GPIOPortP1_Handler(void) __attribute__((weak));
void GPIOPortP2_Handler(void) __attribute__((weak));
void GPIOPortP3_Handler(void) __attribute__((weak));
void GPIOPortP4_Handler(void) __attribute__((weak));
void GPIOPortP5_Handler(void) __attribute__((weak));
void GPIOPortP6_Handler(void) __attribute__((weak));
void GPIOPortP7_Handler(void) __attribute__((weak));
void GPIOPortQ_Handler(void) __attribute__((weak));
void GPIOPortQ1_Handler(void) __attribute__((weak));
void GPIOPortQ2_Handler(void) __attribute__((weak));
void GPIOPortQ3_Handler(void) __attribute__((weak));
void GPIOPortQ4_Handler(void) __attribute__((weak));
void GPIOPortQ5_Handler(void) __attribute__((weak));
void GPIOPortQ6_Handler(void) __attribute__((weak));
void GPIOPortQ7_Handler(void) __attribute__((weak));
void GPIOPortR_Handler(void) __attribute__((weak));
void GPIOPortS_Handler(void) __attribute__((weak));
void PWM1Generator0_Handler(void) __attribute__((weak));
void PWM1Generator1_Handler(void) __attribute__((weak));
void PWM1Generator2_Handler(void) __attribute__((weak));
void PWM1Generator3_Handler(void) __attribute__((weak));
void PWM1Fault_Handler(void) __attribute__((weak));


// Function prototypes for the inline assembly functions
void DisableInterrupts(void);
void EnableInterrupts(void);
uint32_t StartCritical(void);
void EndCritical(uint32_t primask);
void WaitForInterrupt(void);

//*****************************************************************************
//
// The entry point for the application.
//
//*****************************************************************************
extern int main(void);

//*****************************************************************************
//
// Reserve space for the system stack.
//
//*****************************************************************************
static unsigned long pulStack[64];

//*****************************************************************************
//
// The vector table.  Note that the proper constructs must be placed on this to
// ensure that it ends up at physical address 0x0000.0000.
//
//*****************************************************************************
__attribute__ ((section(".isr_vector")))
void (* const g_pfnVectors[])(void) =
{
    (void (*)(void))((unsigned long)pulStack + sizeof(pulStack)),
                                            // The initial stack pointer
    ResetISR,                               // The reset handler
    NMI_Handler,                                  // The NMI handler
    HardFault_Handler,                               // The hard fault handler
    MemManage_Handler,                      // The MPU fault handler
    BusFault_Handler,                      // The bus fault handler
    UsageFault_Handler,                      // The usage fault handler
    0,                                      // Reserved
    0,                                      // Reserved
    0,                                      // Reserved
    0,                                      // Reserved
    SVC_Handler,                      // SVCall handler
    DebugMon_Handler,                      // Debug monitor handler
    0,                                      // Reserved
    PendSV_Handler,                      // The PendSV handler
    SysTick_Handler,                      // The SysTick handler
    GPIOPortA_Handler,                      // GPIO Port A
    GPIOPortB_Handler,                      // GPIO Port B
    GPIOPortC_Handler,                      // GPIO Port C
    GPIOPortD_Handler,                      // GPIO Port D
    GPIOPortE_Handler,                      // GPIO Port E
    UART0_Handler,                      // UART0 Rx and Tx
    UART1_Handler,                      // UART1 Rx and Tx
    SSI0_Handler,                      // SSI0 Rx and Tx
    I2C0_Handler,                      // I2C0 Master and Slave
    PWM0Fault_Handler,                      // PWM Fault
    PWM0Generator0_Handler,                      // PWM Generator 0
    PWM0Generator1_Handler,                      // PWM Generator 1
    PWM0Generator2_Handler,                      // PWM Generator 2
    Quadrature0_Handler,                      // Quadrature Encoder 0
    ADC0Seq0_Handler,                      // ADC Sequence 0
    ADC0Seq1_Handler,                      // ADC Sequence 1
    ADC0Seq2_Handler,                      // ADC Sequence 2
    ADC0Seq3_Handler,                      // ADC Sequence 3
    WDT_Handler,                      // Watchdog timer
    Timer0A_Handler,                      // Timer 0 subtimer A
    Timer0B_Handler,                      // Timer 0 subtimer B
    Timer1A_Handler,                      // Timer 1 subtimer A
    Timer1B_Handler,                      // Timer 1 subtimer B
    Timer2A_Handler,                      // Timer 2 subtimer A
    Timer2B_Handler,                      // Timer 2 subtimer B
    Comp0_Handler,                      // Analog Comparator 0
    Comp1_Handler,                      // Analog Comparator 1
    Comp2_Handler,                      // Analog Comparator 2
    SysCtl_Handler,                      // System Control (PLL, OSC, BO)
    FlashCtl_Handler,                      // FLASH Control
    GPIOPortF_Handler,                      // GPIO Port F
    GPIOPortG_Handler,                      // GPIO Port G
    GPIOPortH_Handler,                      // GPIO Port H
    UART2_Handler,                      // UART2 Rx and Tx
    SSI1_Handler,                      // SSI1 Rx and Tx
    Timer3A_Handler,                      // Timer 3 subtimer A
    Timer3B_Handler,                      // Timer 3 subtimer B
    I2C1_Handler,                      // I2C1 Master and Slave
    Quadrature1_Handler,                      // Quadrature Encoder 1
    CAN0_Handler,                      // CAN0
    CAN1_Handler,                      // CAN1
    CAN2_Handler,                      // CAN2
    Ethernet_Handler,                      // Ethernet
    Hibernate_Handler,                      // Hibernate
    USB0_Handler,                      // USB0
    PWM0Generator3_Handler,                      // PWM Generator 3
    uDMA_Handler,                      // uDMA Software Transfer
    uDMA_Error,                      // uDMA Error
    ADC1Seq0_Handler,                      // ADC1 Sequence 0
    ADC1Seq1_Handler,                      // ADC1 Sequence 1
    ADC1Seq2_Handler,                      // ADC1 Sequence 2
    ADC1Seq3_Handler,                      // ADC1 Sequence 3
    I2S0_Handler,                      // I2S0
    ExtBus_Handler,                      // External Bus Interface 0
    GPIOPortJ_Handler,                      // GPIO Port J
    GPIOPortK_Handler,                      // GPIO Port K
    GPIOPortL_Handler,                      // GPIO Port L
    SSI2_Handler,                      // SSI2 Rx and Tx
    SSI3_Handler,                      // SSI3 Rx and Tx
    UART3_Handler,                      // UART3 Rx and Tx
    UART4_Handler,                      // UART4 Rx and Tx
    UART5_Handler,                      // UART5 Rx and Tx
    UART6_Handler,                      // UART6 Rx and Tx
    UART7_Handler,                      // UART7 Rx and Tx
    0,                                      // Reserved
    0,                                      // Reserved
    0,                                      // Reserved
    0,                                      // Reserved
    I2C2_Handler,                      // I2C2 Master and Slave
    I2C3_Handler,                      // I2C3 Master and Slave
    Timer4A_Handler,                      // Timer 4 subtimer A
    Timer4B_Handler,                      // Timer 4 subtimer B
    0,                                      // Reserved
    0,                                      // Reserved
    0,                                      // Reserved
    0,                                      // Reserved
    0,                                      // Reserved
    0,                                      // Reserved
    0,                                      // Reserved
    0,                                      // Reserved
    0,                                      // Reserved
    0,                                      // Reserved
    0,                                      // Reserved
    0,                                      // Reserved
    0,                                      // Reserved
    0,                                      // Reserved
    0,                                      // Reserved
    0,                                      // Reserved
    0,                                      // Reserved
    0,                                      // Reserved
    0,                                      // Reserved
    0,                                      // Reserved
    Timer5A_Handler,                      // Timer 5 subtimer A
    Timer5B_Handler,                      // Timer 5 subtimer B
    WideTimer0A_Handler,                      // Wide Timer 0 subtimer A
    WideTimer0B_Handler,                      // Wide Timer 0 subtimer B
    WideTimer1A_Handler,                      // Wide Timer 1 subtimer A
    WideTimer1B_Handler,                      // Wide Timer 1 subtimer B
    WideTimer2A_Handler,                      // Wide Timer 2 subtimer A
    WideTimer2B_Handler,                      // Wide Timer 2 subtimer B
    WideTimer3A_Handler,                      // Wide Timer 3 subtimer A
    WideTimer3B_Handler,                      // Wide Timer 3 subtimer B
    WideTimer4A_Handler,                      // Wide Timer 4 subtimer A
    WideTimer4B_Handler,                      // Wide Timer 4 subtimer B
    WideTimer5A_Handler,                      // Wide Timer 5 subtimer A
    WideTimer5B_Handler,                      // Wide Timer 5 subtimer B
    FPU_Handler,                      // FPU
    PECI0_Handler,                      // PECI 0
    LPC0_Handler,                      // LPC 0
    I2C4_Handler,                      // I2C4 Master and Slave
    I2C5_Handler,                      // I2C5 Master and Slave
    GPIOPortM_Handler,                      // GPIO Port M
    GPIOPortN_Handler,                      // GPIO Port N
    Quadrature2_Handler,                      // Quadrature Encoder 2
    Fan0_Handler,                      // Fan 0
    0,                                      // Reserved
    GPIOPortP_Handler,                      // GPIO Port P (Summary or P0)
    GPIOPortP1_Handler,                      // GPIO Port P1
    GPIOPortP2_Handler,                      // GPIO Port P2
    GPIOPortP3_Handler,                      // GPIO Port P3
    GPIOPortP4_Handler,                      // GPIO Port P4
    GPIOPortP5_Handler,                      // GPIO Port P5
    GPIOPortP6_Handler,                      // GPIO Port P6
    GPIOPortP7_Handler,                      // GPIO Port P7
    GPIOPortQ_Handler,                      // GPIO Port Q (Summary or Q0)
    GPIOPortQ1_Handler,                      // GPIO Port Q1
    GPIOPortQ2_Handler,                      // GPIO Port Q2
    GPIOPortQ3_Handler,                      // GPIO Port Q3
    GPIOPortQ4_Handler,                      // GPIO Port Q4
    GPIOPortQ5_Handler,                      // GPIO Port Q5
    GPIOPortQ6_Handler,                      // GPIO Port Q6
    GPIOPortQ7_Handler,                      // GPIO Port Q7
    GPIOPortR_Handler,                      // GPIO Port R
    GPIOPortS_Handler,                      // GPIO Port S
    PWM1Generator0_Handler,                      // PWM 1 Generator 0
    PWM1Generator1_Handler,                      // PWM 1 Generator 1
    PWM1Generator2_Handler,                      // PWM 1 Generator 2
    PWM1Generator3_Handler,                      // PWM 1 Generator 3
    PWM1Fault_Handler                       // PWM 1 Fault
};

//*****************************************************************************
//
// The following are constructs created by the linker, indicating where the
// the "data" and "bss" segments reside in memory.  The initializers for the
// for the "data" segment resides immediately following the "text" segment.
//
//*****************************************************************************
extern unsigned long _etext;
extern unsigned long _data;
extern unsigned long _edata;
extern unsigned long _bss;
extern unsigned long _ebss;

//*****************************************************************************
//
// This is the code that gets called when the processor first starts execution
// following a reset event.  Only the absolutely necessary set is performed,
// after which the application supplied entry() routine is called.  Any fancy
// actions (such as making decisions based on the reset cause register, and
// resetting the bits in that register) are left solely in the hands of the
// application.
//
//*****************************************************************************
void
ResetISR(void)
{
    unsigned long *pulSrc, *pulDest;

    //
    // Copy the data segment initializers from flash to SRAM.
    //
    pulSrc = &_etext;
    for(pulDest = &_data; pulDest < &_edata; )
    {
        *pulDest++ = *pulSrc++;
    }

    //
    // Zero fill the bss segment.
    //
    __asm("    ldr     r0, =_bss\n"
          "    ldr     r1, =_ebss\n"
          "    mov     r2, #0\n"
          "    .thumb_func\n"
          "zero_loop:\n"
          "        cmp     r0, r1\n"
          "        it      lt\n"
          "        strlt   r2, [r0], #4\n"
          "        blt     zero_loop");

    //
    // Enable the floating-point unit.  This must be done here to handle the
    // case where main() uses floating-point and the function prologue saves
    // floating-point registers (which will fault if floating-point is not
    // enabled).  Any configuration of the floating-point unit using DriverLib
    // APIs must be done here prior to the floating-point unit being enabled.
    //
    // Note that this does not use DriverLib since it might not be included in
    // this project.
    //
    HWREG(NVIC_CPAC) = ((HWREG(NVIC_CPAC) &
                         ~(NVIC_CPAC_CP10_M | NVIC_CPAC_CP11_M)) |
                        NVIC_CPAC_CP10_FULL | NVIC_CPAC_CP11_FULL);

    //
    // Call the application's entry point.
    //
    main();
}

//*****************************************************************************
//
// This is the code that gets called when the processor receives a NMI.  This
// simply enters an infinite loop, preserving the system state for examination
// by a debugger.
//
//*****************************************************************************
void NMI_Handler(void){
    //
    // Enter an infinite loop.
    //
    while(1)
    {
    }
}

//*****************************************************************************
//
// This is the code that gets called when the processor receives a fault
// interrupt.  This simply enters an infinite loop, preserving the system state
// for examination by a debugger.
//
//*****************************************************************************
void HardFault_Handler(void){
    //
    // Enter an infinite loop.
    //
    GPIO_PORTE_DATA_R |= 0x02;
    while(1)
    {
    }
}

void MemManage_Handler(void){
    //
    // Enter an infinite loop.
    //
    while(1)
    {
    }
}

void BusFault_Handler(void){
    //
    // Enter an infinite loop.
    //
    while(1)
    {
    }
}

void UsageFault_Handler(void){
    //
    // Enter an infinite loop.
    //
    while(1)
    {
    }
}
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

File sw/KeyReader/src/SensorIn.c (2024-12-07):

/* ================================================== */
/*                      INCLUDES                      */
/* ================================================== */
#include "../inc/SensorIn.h"
#include "../inc/tm4c123gh6pm.h"
#include "stdint.h"
#include "../inc/Timer0A.h"
#include "../inc/Timer1A.h"
#include "../inc/Timer2A.h"
#include "../inc/Timer3A.h"
#include "../inc/main.h"

/* ================================================== */
/*            GLOBAL VARIABLE DEFINITIONS             */
/* ================================================== */
#define NUMBER_OF_SENSORS 24
#define NUMBER_OF_CHANNELS 8
#define ADC_SAMPLING_PERIOD 40000 //1 s
//ssi0 8 channels, then ssi1 8 channels, then ssi2 8 channels
uint16_t ADC_Vals_Buf[NUMBER_OF_SENSORS];
uint8_t ADC_Vals_Buf_idx;

#define CS_DELAY 50

/* ================================================== */
/*            FUNCTION PROTOTYPES (DECLARATIONS)      */
/* ================================================== */


/* ================================================== */
/*                 FUNCTION DEFINITIONS               */
/* ================================================== */

void ADC_IC_Init(void) {
    // Enable SSI0, SSI2, SSI3

    // ---- Configure Port A for SSI0 (PA2-PA5) ----
    // PA2 = SSI0Clk (Clock)
    // PA3 = SSI0Fss (Chip Select/Frame Select, used pe2 instead
    // PA4 = SSI0Rx  (MISO, Master In Slave Out)
    // PA5 = SSI0Tx  (MOSI, Master Out Slave In)

    // ---- Configure Port B for SSI2 (PB4-PB7) ----
    // PB4 = SSI2Clk (Clock)
    // PB5 = SSI2Fss (Chip Select/Frame Select), used pe3 instead
    // PB6 = SSI2Rx  (MISO, Master In Slave Out)
    // PB7 = SSI2Tx  (MOSI, Master Out Slave In)

    // ---- Configure Port D for SSI3 (PD0-PD3) ----
    // PD0 = SSI3Clk (Clock)
    // PD1 = SSI3Fss (Chip Select/Frame Select), using pe4 instead
    // PD2 = SSI3Rx  (MISO, Master In Slave Out)
    // PD3 = SSI3Tx  (MOSI, Master Out Slave In)
    // Enable SSI0, SSI1, SSI2
    SYSCTL_RCGCSSI_R |= (SYSCTL_RCGCSSI_R0 | SYSCTL_RCGCSSI_R2 | SYSCTL_RCGCSSI_R3);  // Enable SSI0, SSI2, and SSI3
    while((SYSCTL_PRSSI_R & (SYSCTL_RCGCSSI_R0 | SYSCTL_RCGCSSI_R2 | SYSCTL_RCGCSSI_R3)) == 0) {}  // Wait until SSI0, SSI2, and SSI3 are ready
    
    // Enable clocks for Port A, B, D
    SYSCTL_RCGCGPIO_R |= (SYSCTL_RCGCGPIO_R0 | SYSCTL_RCGCGPIO_R1 | SYSCTL_RCGCGPIO_R3);  // Enable clocks for Port A, B, D
    while((SYSCTL_PRGPIO_R & (SYSCTL_RCGCGPIO_R0 | SYSCTL_RCGCGPIO_R1 | SYSCTL_RCGCGPIO_R3)) == 0) {}  // Wait until Ports A, B, D are ready

    // ---- Configure Port A for SSI0 (PA2-PA5) ----
    GPIO_PORTA_AFSEL_R |= 0x3C;                    // Enable alt funct on PA2-PA5 
    GPIO_PORTA_DEN_R |= 0x3C;                      // Enable digital I/O on PA2-PA5
    GPIO_PORTA_PCTL_R = (GPIO_PORTA_PCTL_R & 0xFF0000FF) + 0x00222200; // Configure PA2-PA5 as SSI
    GPIO_PORTA_AMSEL_R &= ~0x3C;                  // Disable analog functionality on PA2-PA5
    GPIO_PORTA_DIR_R |= 0x2C;  //make pa2,3,5 out
    GPIO_PORTA_DIR_R &= ~0x10;  //make pa4 in

    // ---- Configure Port B for SSI2 (PB4-PB7) ----
    GPIO_PORTB_AFSEL_R |= 0xF0;                    // Enable alt funct on PB4-PB7
    GPIO_PORTB_DEN_R |= 0xF0;                      // Enable digital I/O on PB4-PB7
    GPIO_PORTB_PCTL_R = (GPIO_PORTB_PCTL_R & 0x0000FFFF) + 0x22220000; // Configure PB4-PB7 as SSI
    GPIO_PORTB_AMSEL_R &= ~0xF0;                   // Disable analog functionality on PB4-PB7
    GPIO_PORTB_DIR_R |= 0xB0;  //make pb 7,5,4 out 11X1XXX
    GPIO_PORTB_DIR_R &= ~0x40;  //make pb6 in   XX0XXXXX
    //GPIO_PORTB_PDR_R |= 0x80;  // Enable pull-down on PB7


    // Set PB7 (SPI2 MOSI) to 8mA drive strength
    //GPIO_PORTB_DR8R_R |= 0x80;  // 0x80 = 0b10000000, enables 8mA drive on PB7


    // ---- Configure Port D for SSI3 (PD0-PD3) ----
    GPIO_PORTD_AFSEL_R |= 0x0F;                    // Enable alt funct on PD0-PD3
    GPIO_PORTD_DEN_R |= 0x0F;                      // Enable digital I/O on PD0-PD3
    GPIO_PORTD_PCTL_R = (GPIO_PORTD_PCTL_R & 0xFFFF0000) + 0x00001111; // Configure PD0-PD3 as SSI
    GPIO_PORTD_AMSEL_R &= ~0x0F;                   // Disable analog functionality on PD0-PD3
    GPIO_PORTD_DIR_R |= 0x0B;  //make pd0,1,4 out XXXX1X11
    GPIO_PORTD_DIR_R &= ~0x04;  //pd2 in XXXXX0XX
    GPIO_PORTD_PUR_R |= 0x08; 
    // ------------------- Configure SSI0 ---------------------
    SSI0_CR1_R = 0x00000000;    // Disable SSI to configure
    SSI0_CC_R = 0;  //use system clock
    SSI0_CPSR_R = 10;           // Set CPSR = 10 (prescale divisor)
    SSI0_CR0_R = 0;             // Clear the CR0 register
    SSI0_CR0_R |= (7 << 8);     // Set SCR = 7 for 1 MHz SSI clock
    SSI0_CR0_R |= (0 << 7);     // Set SPH = 0 (capture data on the first clock edge)
    SSI0_CR0_R |= (0 << 6);     // Set SPO = 0 (clock is idle low)
    SSI0_CR0_R |= (0 << 4);     // Set FRF = 00 (Freescale SPI format)
    SSI0_CR0_R |= 0x07;         // Set DSS = 8 bits (0x07 = 7 for 8-bit data)
    SSI0_CR1_R |= 0x00000002;   // Enable SSI


    //SSI0_CC_R = (SSI0_CC_R & ~SSI_CC_CS_M) + SSI_CC_CS_SYSPLL;

    // ------------------- Configure SSI2 ---------------------
    SSI2_CR1_R = 0x00000000;  // Disable SSI to configure
    SSI2_CC_R = 0;  //use system clock
    SSI2_CPSR_R = 10;       // Set CPSR = 4 (prescale divisor)
    SSI2_CR0_R = 0;           // Clear the CR0 register
    SSI2_CR0_R |= (7 << 8);  // Set SCR = 12 (serial clock rate)
    SSI2_CR0_R |= (0 << 7);   // Set SPH = 0 (capture data on the first clock edge)
    SSI2_CR0_R |= (0 << 6);   // Set SPO = 0 (clock is idle low)
    SSI2_CR0_R |= (0 << 4);   // Set FRF = 00 (Freescale SPI format)
    SSI2_CR0_R |= 0x07;       // Set DSS = 8 bits (0x07 = 7 for 8-bit data)
    SSI2_CR1_R |= 0x00000002; // Enable SSI

    // ------------------- Configure SSI3 ---------------------
    SSI3_CR1_R = 0x00000000;  // Disable SSI to configure
    SSI3_CC_R = 0;  //use system clock
    SSI3_CPSR_R = 10;       // Set CPSR = 4 (prescale divisor)
    SSI3_CR0_R = 0;           // Clear the CR0 register
    SSI3_CR0_R |= (7 << 8);  // Set SCR = 12 (serial clock rate)
    SSI3_CR0_R |= (0 << 7);   // Set SPH = 0 (capture data on the first clock edge)
    SSI3_CR0_R |= (0 << 6);   // Set SPO = 0 (clock is idle low)
    SSI3_CR0_R |= (0 << 4);   // Set FRF = 00 (Freescale SPI format)
    SSI3_CR0_R |= 0x07;       // Set DSS = 8 bits (0x07 = 7 for 8-bit data)
    SSI3_CR1_R |= 0x00000002; // Enable SSI
}
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

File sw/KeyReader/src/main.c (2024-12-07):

/* ================================================== */
/*                      INCLUDES                      */
/* ================================================== */
#include "../inc/main.h"
#include <stdint.h>
#include "../inc/tm4c123gh6pm.h"
#include "../inc/PLL.h"
#include "../inc/SensorIn.h"
#include "../inc/Communication.h"
#include "../inc/Notes.h"
#include "../inc/Timer0A.h"
#include "../inc/Timer5A.h"
#include "../inc/LaunchPad.h"
#include "../inc/UART.h"

/* ================================================== */
/*            GLOBAL VARIABLE DEFINITIONS             */
/* ================================================== */
bool samplesTaken = false;
/* ================================================== */
/*            FUNCTION PROTOTYPES (DECLARATIONS)      */
/* ================================================== */


void Clock_Delay1ms(uint32_t n);

void HeartBeat(void);
void PortE_Init(void);

void intToStr(int num, char str[12]);
char int_str_buf[12];

char keyNames[24][5] = {
  "G#3", "A3", "A#3", "B3", "C4", "C#4", "D4", "D#4", // SSI 0 | ADC3
  "E4", "F4", "F#4", "G4", "G#4", "A4", "A#4", "B4",  // SSI 2 | ADC1 
  "C3", "C#3", "D3", "D#3", "E3", "F3", "F#3", "G3"   // SSI 3 | ADC2
};
/* ================================================== */
/*                    MAIN FUNCTION                   */
/* ================================================== */
int main(void){
	startupDelay();
	DisableInterrupts();
	PLL_Init(Bus80MHz);    // bus clock at 80 MHz
  //LaunchPad_Init();
	PortE_Init();
	SensorsInit();
	UART_Init();
	Chip_to_Chip_Init();
  //TestSendingMessages_Init();
	Notes_Init();
	//Timer5A_Init(HeartBeat, 80000000, 7);
	EnableInterrupts();
	//SendTestMessage();
	//GPIO_PORTE_DATA_R |= 0x02;
	while(1){
		// if(samplesTaken){
		// 	DisableInterrupts();
		// 	for(int i = 0; i < NUMBER_OF_SENSORS; i++){
    //     UART_OutString(keyNames[i]);
    //     UART_OutString(": ");
		// 		intToStr(ADC_Vals_Buf[i], int_str_buf);
		// 		UART_OutString(int_str_buf);
		// 	}
			//GPIO_PORTE_DATA_R |= 0x2;
			//while(1){}
		//}
		Notes_State_Update();
	}
}


/* ================================================== */
/*                 FUNCTION DEFINITIONS               */
/* ================================================== */
void HeartBeat(void){
	GPIO_PORTE_DATA_R ^= 0x20;
 }
void startupDelay(void){
  for(uint16_t i = 0; i < UINT16_MAX; i++){}
}

void Clock_Delay(uint32_t ulCount){
  while(ulCount){
    ulCount--;
  }
}

void Clock_Delay1ms(uint32_t n){
  while(n){
    Clock_Delay(23746);  // 1 msec, tuned at 80 MHz, originally part of LCD module
    n--;
  }
}

void PortE_Init(void){
	SYSCTL_RCGCGPIO_R |= SYSCTL_RCGCGPIO_R4;//turn on porte
	while((SYSCTL_PRGPIO_R & SYSCTL_RCGCGPIO_R4) == 0){}

	//make pe0-4 gigital outs
	GPIO_PORTE_AMSEL_R &= ~0xFF;
	GPIO_PORTE_AFSEL_R &= ~0xFF;
	GPIO_PORTE_PCTL_R &= ~0xFFFFFFFF;
	GPIO_PORTE_DEN_R |= 0xFF;
	GPIO_PORTE_DIR_R |= 0xFF;

	GPIO_PORTE_DATA_R |= 0x04;//pe2 on
    GPIO_PORTE_DATA_R |= 0x08;//pe3 on
    GPIO_PORTE_DATA_R |= 0x10;//pe4 on
}
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
